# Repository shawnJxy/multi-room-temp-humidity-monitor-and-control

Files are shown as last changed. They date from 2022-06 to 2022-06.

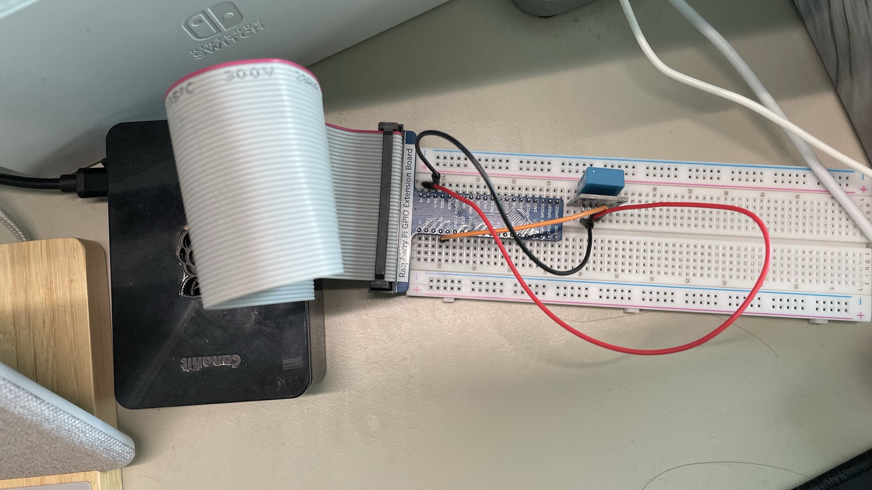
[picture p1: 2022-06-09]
1.Doc/images/Pi_setup.JPEG

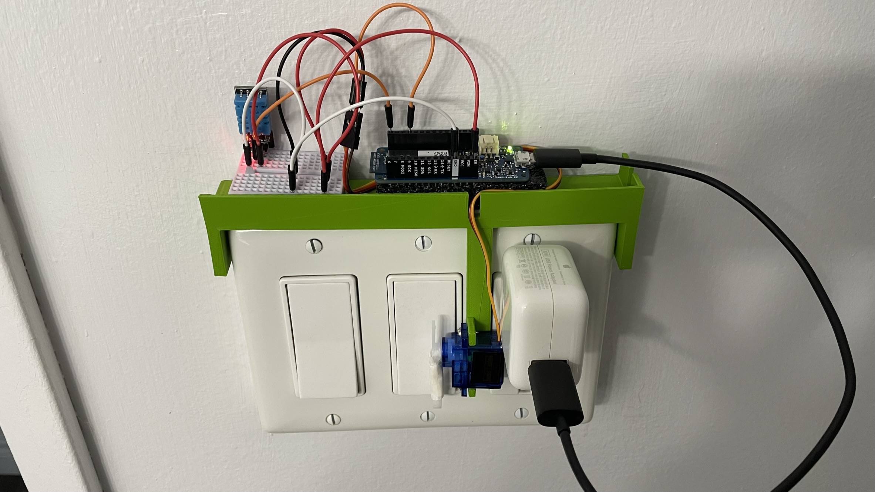
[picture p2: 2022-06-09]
1.Doc/images/MKR1000_setup.JPEG

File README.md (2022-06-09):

# Multi-room Temperature and Humidity Monitor and Control (w/ ThingsBoard)
This repository is created as a part for fulfilling the requirement to the course SEP 769 Cyber Physical Systems. 

A demostration video can be found [here](https://youtu.be/9qk1WlgCuhU).

## Introduction
This project focuses on setting up a multi-room temperature and humidity monitoring and control system. 
An Arduino MKR1000 and a Raspberry Pi was used in this project to collect data from DHT11 sensor and controls the actuators. A TP-Link HS110 and a servo motor were used as the actuators in this project. A circulator fan was connected to the HS110 smart plug whileas the servo motor was used to control a wall switch for a exhaust fan. 

The ThingsBoard community edition was used to provide the MQTT Broker, data storage, RPC Calls and dashboard interface. Both MKR1000 and Raspberry Pi were congifured to talk to the MQTT Broker hosted by ThingsBoard to update the temperature and humidity readings. Remote procedure calls (RPC) was used to send the remote control signals to both edge devices. Two local automatic control loop were also setup on each device to perform automatic actions by default

## Sample Setup Image


## Material Used
- Raspberry Pi 4
- Arduino MKR1000 WIFI
- Breadboard (x2)
- Servo Motor (SG90)
- TP-Link Smart Plug HS110
- Air Circulator Fan
- 3D-printed Switch Mount 

## Library used
### Arduino
- [ThingsBoard SDK](https://github.com/thingsboard/thingsboard-arduino-sdk)
- [Adafruit DHT sensor](https://github.com/adafruit/DHT-sensor-library)
- [ArduinoJson](https://github.com/bblanchon/ArduinoJson)
- [pubsubClient](https://github.com/knolleary/pubsubclient)

### Python
- [Python Kasa](https://github.com/python-kasa/python-kasa)
- [Adafruit CircuitPython DHT](https://github.com/adafruit/Adafruit_CircuitPython_DHT)
- [Paho MQTT](https://github.com/eclipse/paho.mqtt.python)

## Code
### Arduino Code
The sketch used in this project can also be found on [here](https://create.arduino.cc/editor/shawnjxy/407df74e-2717-4218-bc97-e27b5a20a7ff/preview). 

## System Schematic
### System Block Diagram
system_block

### Local Automatic Logic
local_control_logic

### Cloud Control Logic
cloud_control_logic

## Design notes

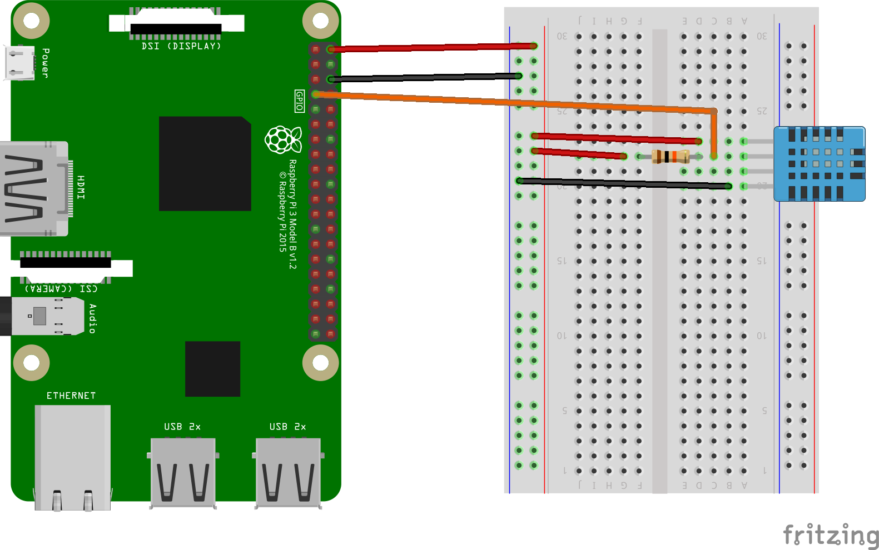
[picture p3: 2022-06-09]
1.Doc/diagrams/connection_schematics/Pi_connection.png

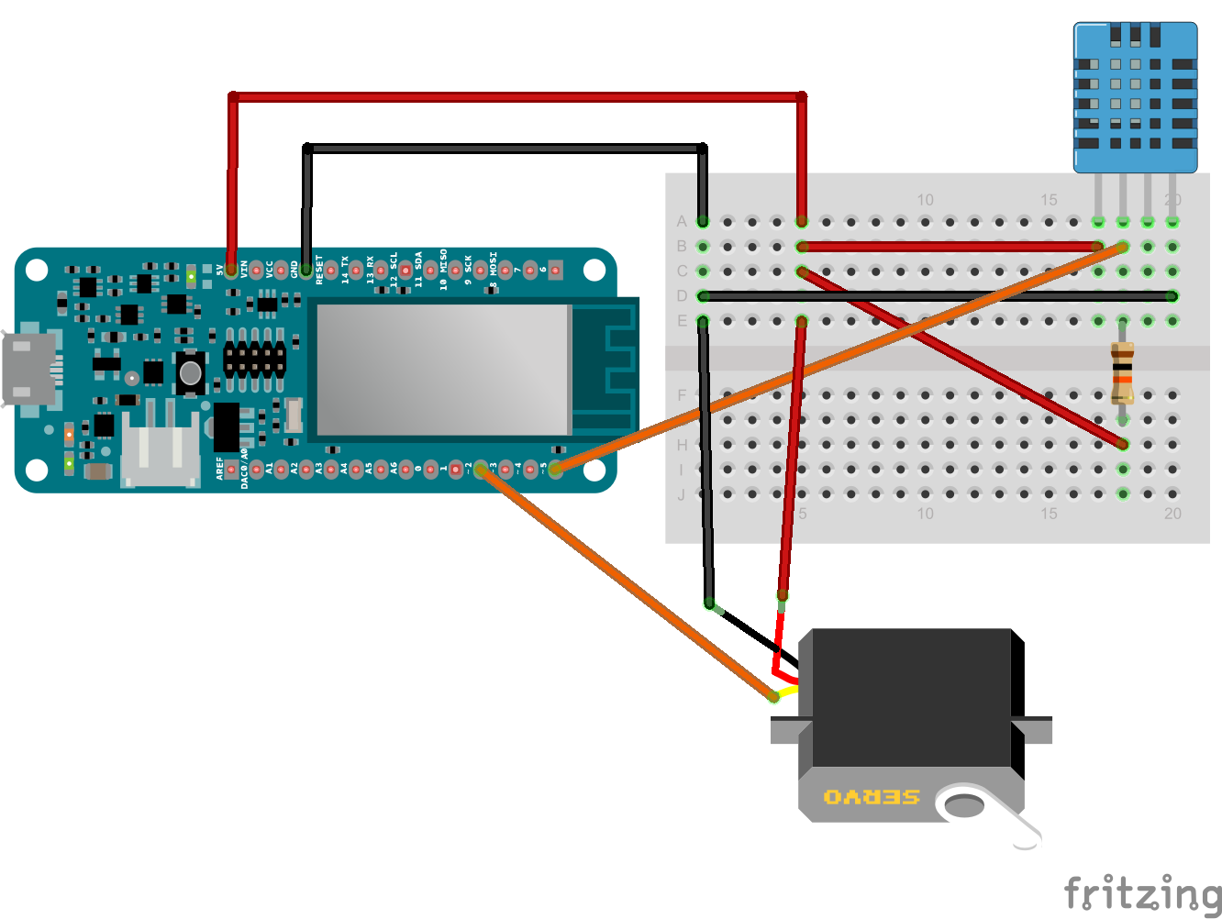
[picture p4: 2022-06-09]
1.Doc/diagrams/connection_schematics/MKR1000_connection.png

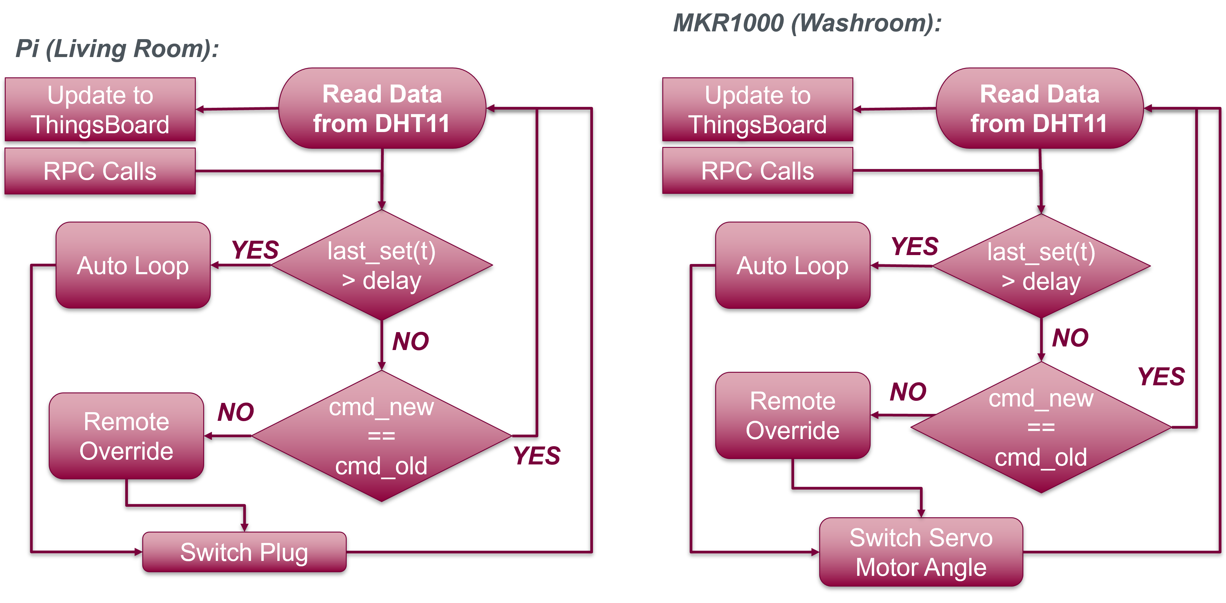
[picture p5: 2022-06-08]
1.Doc/diagrams/flowchart/cloud_control_logic.png

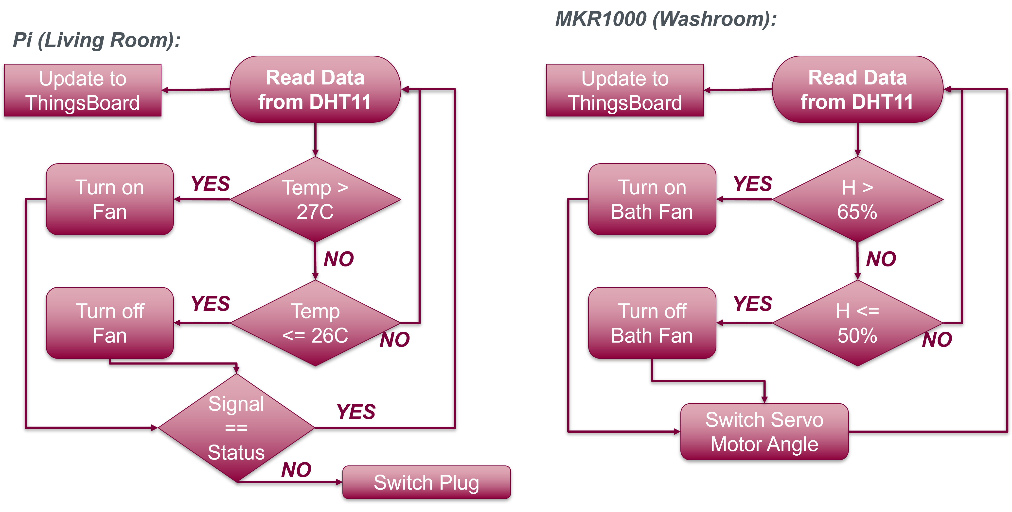
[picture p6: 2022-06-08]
1.Doc/diagrams/flowchart/local_control_logic.png

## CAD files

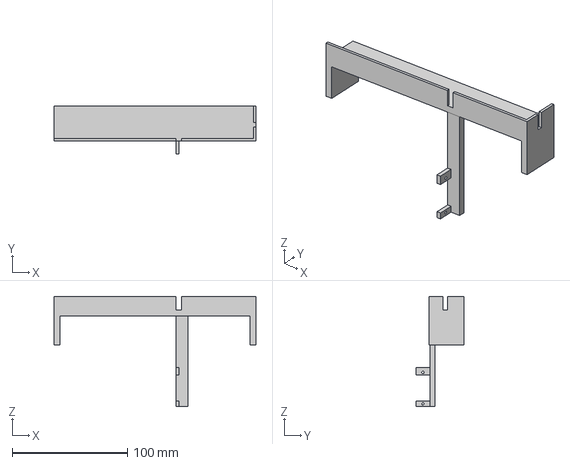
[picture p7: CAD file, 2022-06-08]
3.CAD Model/CPS_Project_Switch Mount v4.step
175.0 x 41.3 x 95.5 mm

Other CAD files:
3.CAD Model/CPS_Project_Switch Mount v4.f3d
3.CAD Model/CPS_Project_Switch Mount v4.stl

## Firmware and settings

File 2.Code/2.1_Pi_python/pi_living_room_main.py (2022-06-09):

import time
import sys
import board
import adafruit_dht
import paho.mqtt.client as mqtt
import json
import asyncio
from kasa import SmartPlug
import dht
        
#setup smart plug entity
plug = SmartPlug("192.168.4.44")


#setup MQTT with thingsboard
THINGSBOARD_HOST = 'demo.thingsboard.io'
ACCESS_TOKEN = 'rK5mm66QTtCNOrAtHyzf'


def on_connect(client, userdata, rc, *extra_parms):
    print('Connected with result code' + str(rc))
    # Subscribing to receive RPC requests
    client.subscribe('v1/devices/me/rpc/request/+')
    #time.sleep(1)
    

def indoorStatus():
    t,h = dht.getdata()
    msg = str({'Temperature':t,'Humidity':h})
    print(msg)
    return msg

async def plugUpdate():
    await plug.update()
    if plug.is_on == True:
        #global plugStatus
        plugStatus = True
    else:
        #global plugStatus
        plugStatus = False
    print ("plugStatus: " + str(plugStatus))
    return plugStatus   
    
async def plugSwitch(plugSet):
    if plugSet == True:
        await plug.turn_on()
        print ("Plug On")
    else:
        await plug.turn_off()
        print ("Plug Off")

async def plugAuto():
    global plugSet_old
    global plugStatus
    t, h = dht.getdata()
    if t > 27:
        await plug.turn_on()
        plugSet_old = True
        plugStatus = True
        print ("Auto Fan: On")
    elif t <= 27:
        await plug.turn_off()
        plugSet_old = False
        plugStaus = False
        print ("Auto Fan: Off")
        

def on_message(client, userdata, msg):
    print ('Topic: ' + msg.topic + '\nMessage: ' + str(msg.payload))
    # Decode JSON request
    data = json.loads(msg.payload)
    # Check request method
    if data['method'] == 'getValue':
        if plugStatus == False:
            client.publish(msg.topic.replace('request', 'response'), json.dumps({'data': 0}), 1)
        else:          
            client.publish(msg.topic.replace('request', 'response'), json.dumps({'data': 1}), 1)
    elif data['method'] == 'setValue':
        global plugSet
        global plugSet_time
        if data['params'] == True:
            #global plugSet
            plugSet = True
            plugSet_time = time.time()
            print ("plugSet: " + str(plugSet))
        elif data['params'] == False:
            #global plugSet
            plugSet = False
            plugSet_time = time.time()
            print ("plugSet: " + str(plugSet))

client = mqtt.Client()
#Register connect callback
client.on_connect = on_connect
# Registed publish message callback
client.on_message = on_message
# Set access token
client.username_pw_set(ACCESS_TOKEN)
# Connect to ThingsBoard using default MQTT port and 60 seconds keepalive interval
client.connect(THINGSBOARD_HOST, 1883, 60)


async def main():
    global plugStatus
    global plugSet
    global plugSet_old
    global plugSet_time
    #check plug status
    plugStatus = await plugUpdate()
    print ("plug Status: " + str(plugStatus))
    #initialize plugSet
    plugSet_old = plugStatus
    plugSet = plugStatus
    plugSet_time = 0
    print ("initialized" + str(plugSet_old))
    while client.loop() ==0:
        try: 
            #publish room temp and humidity data
            client.publish('v1/devices/me/telemetry', indoorStatus(), qos=0, retain=False)
            print("payload sent")
            #update plug status
            #print (str(time.time()))
            #print (str(plugSet_time))
            #delta = time.time() - plugSet_time
            #print ("timeDelat: " + str(delta))
            if plugSet_time == 0:
                await plugAuto()
            elif time.time() - plugSet_time  > 3600:
                await plugAuto()
                plugSet_time = 0
            else:
                if plugSet == plugSet_old:
                    print ("plug Set: No Action")
                else:
                    await plugSwitch(plugSet)
                    plugSet_old = plugSet
                    plugSet_time = time.time()
                    print ("plug Set" + str(plugSet))              
            time.sleep(2)
        except KeyboardInterrupt:
            print("Disconnect")
            client.disconnect()

if __name__ == "__main__":
    asyncio.run(main())

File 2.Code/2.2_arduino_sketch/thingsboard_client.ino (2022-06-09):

#include "arduino_secrets.h"
// ArduinoJson - Version: Latest 
#include <ArduinoJson.h>
#include <ArduinoJson.hpp>

// PubSubClient - Version: Latest 
#include <PubSubClient.h>

// ThingsBoard - Version: Latest 
#include <ThingsBoard.h>

// ArduinoHttpClient - Version: Latest 
#include <ArduinoHttpClient.h>

// Servo - Version: Latest
#include <Servo.h>

// DHT sensor library - Version: Latest
#include <DHT.h>
#include <DHT_U.h>

// Helper macro to calculate array size
#define COUNT_OF(x) ((sizeof(x)/sizeof(0[x])) / ((size_t)(!(sizeof(x) % sizeof(0[x])))))

#define DHTPIN 5 //digital pin connected to DHT sensor
#define DHTTYPE DHT11 //define DHT sensor type

Servo servo1;

/*
  ArduinoMqttClient - WiFi Simple Sender

  This example connects to a MQTT broker and publishes a message to
  a topic once a second.

  The circuit:
  - Arduino MKR 1000, MKR 1010 or Uno WiFi Rev.2 board

  This example code is in the public domain.
*/

#include <ArduinoMqttClient.h>
#include <WiFi101.h>

// Baud rate for debug serial
#define SERIAL_DEBUG_BAUD    9600

///////you may enter your sensitive data in the Secret tab/arduino_secrets.h
char ssid[] = SECRET_SSID;
char pass[] = SECRET_PASS;

WiFiClient wifiClient;
//MqttClient mqttClient(wifiClient);

//make sure the TOKEN matches with the acess token generated on ThingsBoard
#define TOKEN               "oMwggDe4HTVGjRZNh1wQ"
// ThingsBoard server instance.
#define THINGSBOARD_SERVER  "demo.thingsboard.io"

// Baud rate for debug serial
#define SERIAL_DEBUG_BAUD    115200

// Initialize ThingsBoard instance
ThingsBoard tb(wifiClient);

const long interval = 1000;
unsigned long previousMillis = 0;

// Main application loop delay
int quant = 20;
// Time passed after temperature/humidity data was sent, milliseconds.
int send_passed = 0;
// Period of sending a temperature/humidity data.
int send_delay = 2000;
// Set to true if application is subscribed for the RPC messages.
bool subscribed = false;

//define dht and servo motor devices 
DHT dht(DHTPIN, DHTTYPE);

int servopin = 2;

//set variable to store cloud commands
bool switch_Set = false;
//set variable to store last switch state
bool switch_last = false;
//set variable to store last switch state
bool switch_Set_local = false;
// Time passed after temperature/humidity data was sent, milliseconds.
int switch_Set_passed = 0;
// Period of sending a temperature/humidity data.
int switch_Set_delay = 60000;

// Processes function for RPC call "setValue"
// RPC_Data is a JSON variant, that can be queried using operator[]
// See https://arduinojson.org/v5/api/jsonvariant/subscript/ for more details
RPC_Response processDelayChange(const RPC_Data &data)
{
  Serial.println("Received the set delay RPC method");

  // Process data
  //tmp = String(data);
  //Serial.println(tmp);
  switch_Set = data;
  switch_Set_passed = 0;

  return RPC_Response(NULL, switch_Set);
}

// Processes function for RPC call "getValue"
// RPC_Data is a JSON variant, that can be queried using operator[]
// See https://arduinojson.org/v5/api/jsonvariant/subscript/ for more details
RPC_Response processGetDelay(const RPC_Data &data)
{
  Serial.println("Received the get value method");

  return RPC_Response(NULL, switch_last);
}

// RPC handlers
RPC_Callback callbacks[] = {
  { "setValue",         processDelayChange },
  { "getValue",         processGetDelay },
};

void setup() {
  //servo pin setup
  servo1.attach(servopin);
  
  //Initialize serial and wait for port to open:
  Serial.begin(9600);
  //Disable following for running with USB power supply
  //while (!Serial) {
    //; // wait for serial port to connect. Needed for native USB port only
  //}

  // attempt to connect to Wifi network:
  Serial.print("Attempting to connect to WPA SSID: ");
  Serial.println(ssid);
  while (WiFi.begin(ssid, pass) != WL_CONNECTED) {
    // failed, retry
    Serial.print(".");
    delay(5000);
  }

  Serial.println("You're connected to the network");
  Serial.println();
  
  dht.begin();
}


void loop() {
  delay(quant);
  send_passed += quant;
  switch_Set_passed += quant;
  
  //check DHT11 reading
  float h = dht.readHumidity();        // read humidity
  float t = dht.readTemperature();     // read temperature
  if (isnan(h) || isnan(t) ) {
    Serial.println(F("Failed to read from DHT sensor!"));
    return;
  }
  // for debug use
  // Serial.print(h);
  // Serial.print("\t");
  // Serial.println(t);
  
  //auto fan control
  if (switch_Set_passed > switch_Set_delay) {
    if (h > 65) {
      switch_Set_local = true;
    } else if (h <= 50 ){
      switch_Set_local = false;
    } else {
      ;
    }
    if (switch_Set_local != switch_last){
      switchControl(switch_Set_local);
      switch_last = switch_Set_local;
    } else {
      ;
    }
  } else {
    //Serial.println(switch_Set);
    //Serial.println(switch_last);
    if (switch_Set == switch_last ) {
      ;
    } else {
      Serial.println("Manual Override");
      switchControl(switch_Set);
    }
  }
  
  // // Reconnect to WiFi, if needed
  // if (WiFi.status() != WL_CONNECTED) {
  //   reconnect();
  //   return;
  // }

  // Reconnect to ThingsBoard, if needed
  if (!tb.connected()) {
    subscribed = false;

    // Connect to the ThingsBoard
    Serial.print("Connecting to: ");
    Serial.print(THINGSBOARD_SERVER);
    Serial.print(" with token ");
    Serial.println(TOKEN);
    if (!tb.connect(THINGSBOARD_SERVER, TOKEN)) {
      Serial.println("Failed to connect");
      return;
    }
  }

    // Subscribe for RPC, if needed
  if (!subscribed) {
    Serial.println("Subscribing for RPC...");

    // Perform a subscription. All consequent data processing will happen in
    // callbacks as denoted by callbacks[] array.
    if (!tb.RPC_Subscribe(callbacks, COUNT_OF(callbacks))) {
      Serial.println("Failed to subscribe for RPC");
      return;
    }

    Serial.println("Subscribe done");
    subscribed = true;
  }

    // Check if it is a time to send DHT22 temperature and humidity
  if (send_passed > send_delay) {
    Serial.println("Sending data...");

    // Uploads new telemetry to ThingsBoard using MQTT. 
    // See https://thingsboard.io/docs/reference/mqtt-api/#telemetry-upload-api 
    // for more details

    if (isnan(h) || isnan(t) ) {
      Serial.println(F("Failed to read from DHT sensor!"));
    } else {
      tb.sendTelemetryFloat("temperature", t);
      tb.sendTelemetryFloat("humidity", h);
    }

    send_passed = 0;
  }

  // Process messages
  tb.loop();
  
  //delay(2000);
}

void switchControl(bool cmd) {
  Serial.println(cmd);
  if (cmd == 1) {
    servo1.write(145);
    switch_last = true;
    Serial.println("Bath Fan Switch On");
  } else if (cmd == 0){
    servo1.write(10);
    switch_last = false;
    Serial.println("Bath Fan Switch Off");
  }
}

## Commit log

2022-06-08 Upload CAD model for switch mount
    stl, f3d, step uploaded
    [CPS_Project_Switch Mount v4.f3d, CPS_Project_Switch Mount v4.step, CPS_Project_Switch Mount v4.stl]
2022-06-08 Update directory
    [CPS_Project_Switch Mount v4.f3d, CPS_Project_Switch Mount v4.step, CPS_Project_Switch Mount v4.stl]
2022-06-09 Upload ThingsBoard components
    Exported configured ThingsBoard dashboard and device profiles used in this project.
2022-06-09 Upload schematics and images
    Hardware connection schematics, actual setup photos
2022-06-09 Upload core codes
    codes for Raspberry Pi and Arduino
2022-06-09 Update README.md
    Include Arduino code share link, demonstration video
